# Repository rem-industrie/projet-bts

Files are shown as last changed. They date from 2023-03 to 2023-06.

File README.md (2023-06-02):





## Projet bts
## Contenu github
* [Info General](#Info-General)
* [Contenu](#Contenu)
* [Technologies](#technologies)
* [Schéma structurel](#Schéma-structurel)
* [Carte](#Carte)
* [organigramme](#organigramme)
* [Boîtier 3D](#Boîtier-3D)
* [Setup](#setup)

## Info General
Ce projet consiste à capter le courant et une fois fait le renvoyer sur une passerelle MQTT envoye en RS232.

## Contenu
Ce github contient:
* Fichier stl et gcode
* Fichier ARES ISIS.
* Documentation
	
## Technologies
Projet est crée avec:
* Un arduino uno
* Alimenté en +28V
* Carte A4049 (capteur de courant)

## Schéma structurel

schema1
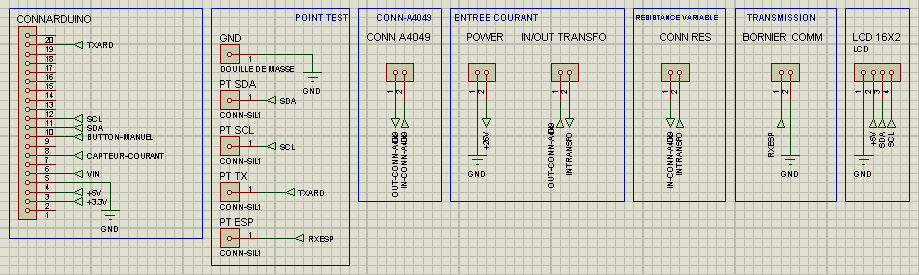
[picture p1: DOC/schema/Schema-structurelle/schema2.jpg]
schema2


## Carte
ares

## organigramme
projet bts

## Setup
Pour cloner le projet:

* ## Boîtier 3D




```
gh repo clone rembot-industrie/projet-bts

```

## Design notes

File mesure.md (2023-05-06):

## Projet bts

## Type mesure:
* [1. Capteur ASC712](#1.-Capteur-ASC712)
* [2. Mesure RS232](#2.-Mesure-RS232)
* [3. Mesure autre](#3.-Mesure-autre)
* [4. Test capteur](#4.Test-capteur)

## 1. Capteur ASC712

| Capteur : | |
|  :--- | :--- |
| Tension ALIM  | +5V |
| Tension à vide  | +2.50V |
| Sensibilité | 40mV/A |
| Marche d'erreur | ±0.8% |

Formule pour obtenir la Tension à partir du courant:
- courant(A) x sensibilité(40mV)

| Tension |  **Mesure Capteur(V)** |  **Mesure Capteur(A)** | Calcul |
| :--- | :--- | :---: | :---: |
| +0V | +2,50V | +0A | +0V |
| +5V | +2,50V | +0.07A | +0.028V |
| +9V | +2,51V | +0.25A | +0.1V |
| +15V | +2,51V | +0.31A | +0.124V |

## 2. Mesure RS232
Ce projet consiste à capter le courant et une fois fais le renvoyer sur une passerelle MQTT envoyer en RS232.
mesure final test

- Regulateur

| Pins | Tension |
| :--- | :--- |
| ADJ(1) | +6.22V |
| VO(2) | +7.50V | 
| VIN(3) | +15V (change selon l'alim)|

- Mesure Transmission:

| | Tension |
| :--- | :--- |
| TX | +4,70V |
| ESP | +3.37V | 
| SCL | +4.99V |
| SDA | +4.99V |

- Button:

| | Tension |
| :--- | :--- |
| Entré | +4.95V |
| Sortie | +1.80V |

- Capteur:

| | Tension |
| :--- | :--- |
| Vcc | +5V |
| Out | +2.5V voir +2.49V  |

- Mesure:

| | Tension |
| :--- | :--- |
| Vin-ard | +7,47V |
| +5 ard | +5V |
| Alim-led | +2.10V |
| led-led | +4.70V |

## 4. Test capteur

| Nombre ampoule(s) 2W |  Nombre ampoule(s) 10W |  **Mesure Capteur(A)** | Calcul | Tension(V) |
| :--- | :--- | :---: | :---: | :---: |
| 0 | 0 | +0A | +0V | +2.49V |
| 0 | 1 | +0.80A | +0.8V | +2.52V |
| 0 | 2 | +1.66A | +1.6V | +2.56V |
| 1 | 2 | +1.90A | +1.84V | +2.57V |
| 2 | 2 | +2.14A | +2.08V | +2.58V |
| 3 | 2 | +2.39A | +2.32V | +2.59V |

Calcul: P / U

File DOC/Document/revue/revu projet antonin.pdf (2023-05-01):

Antonin
Barreau

# Revu de projet

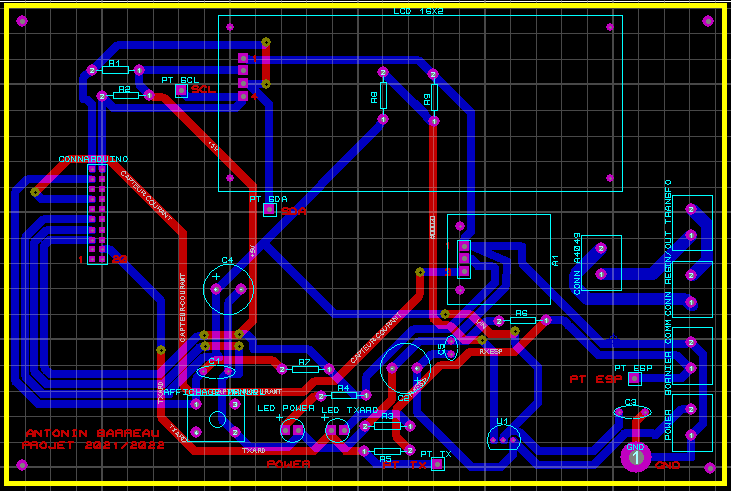
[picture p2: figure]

Lycée Pierre de Coubertin
Année 2022-2023
1/18

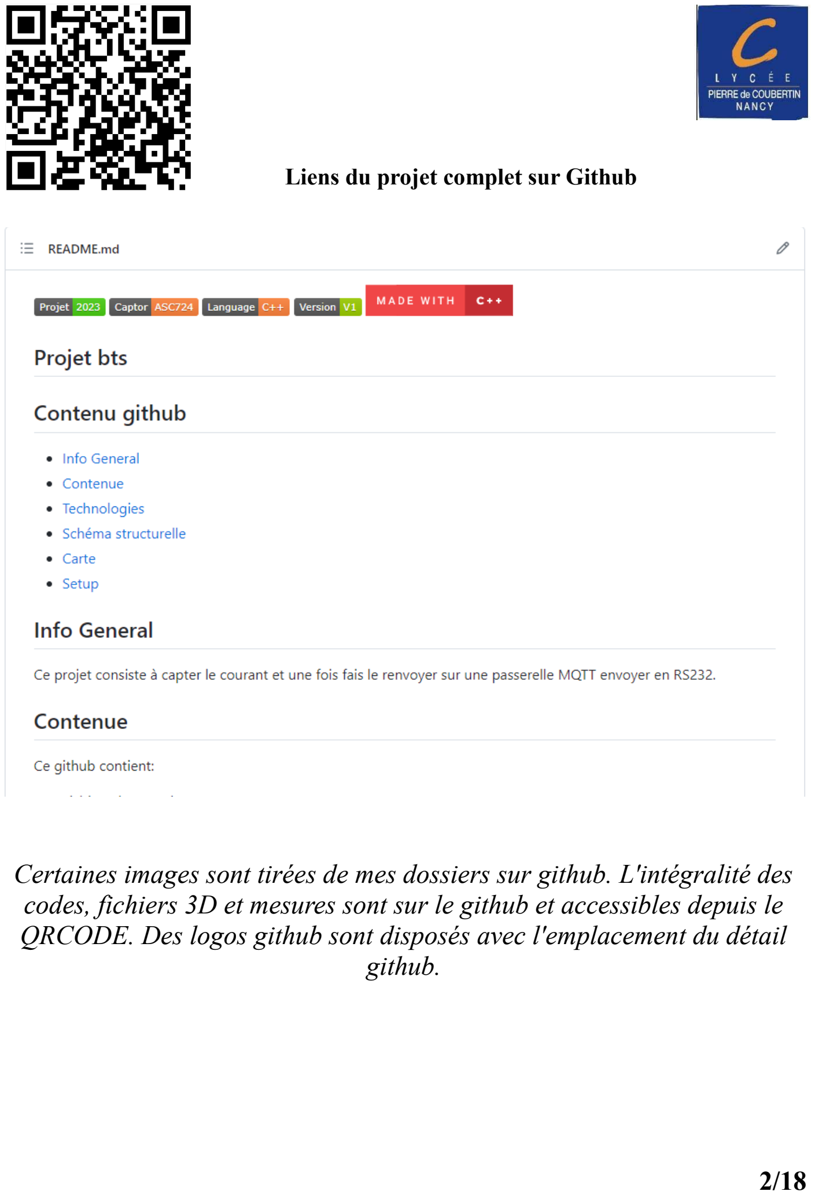
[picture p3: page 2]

Liens du projet complet sur Github

Certaines images sont tirées de mes dossiers sur github. L'intégralité des codes, fichiers 3D et mesures sont sur le github et accessibles depuis le QRCODE. Des logos github sont disposés avec l'emplacement du détail github.

2/18

# Sommaires :

## Projet globale :

- Présentation projet globale | page 4
. Commanditaire du projet | page 5

## Sous projet :

- Présentation sous projet | page 6
- Les composants utilisé | page 7
- A4049 | page 8
- Étude des composants | page 9
- La mise en œuvres du projet | page 10
(phase de test et problème rencontré, mesures)

## Conception :

- Schéma structurelle | page 11
- Conception de la carte à l'aide de logiciel assisté | page 14
- Étude du programme | page 15
- Boîtier 3D | page 17

3/18

# Projet Globale :

par le BUT GEII. Il faudra réaliser un prototype avec les solutions qui nous seront imposées, ou chercher les plus appropriées (micro-contrôleur ex : arduino, esp, raspberry), avec différents capteurs, et ensuite envoyer sur un serveur MQTT réalisé par le BUT.

Le projet est découpé en plusieurs sous-parties :

- Aide au dimensionnement des dissipateurs thermiques
- Aide au dimensionnement du transformateur d'alimentation (mon projet)

Toutes les cartes seront alimentées par une carte d'alimentation qui fourni du +27V (environ), fournie par l’établissement et qui régule la tension selon le contrôleur et la carte.

4/18

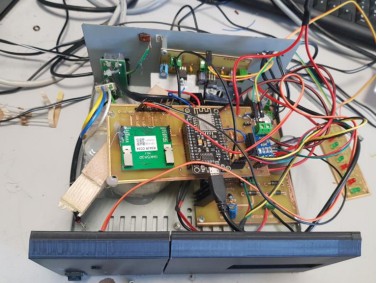
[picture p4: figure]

# Commanditaire :

Pour ce projet, le lycée Pierre de Coubertin est en partenariat avec la formation GEII « Génie électrique et informatique industrielle ». Monsieur François Gremillet, professeur d'électronique dans le lycée Pierre de Coubertin et qui intervient dans la formation GEII.

Un partenariat a vu le jour suite à la présentation de son projet « station audio » qui met en œuvre le fonctionnement de nombreux composants électroniques étudiés dans la formation.

La formation :

Le but GEII est formation de niveau BAC+3 (licence). Cette formation est sur 3 ans avec :

- 600h de projet.
- 30h-33h de cours /semaine
- 22 à 26 semaines de stage.
- Travaux de groupe.

5/18

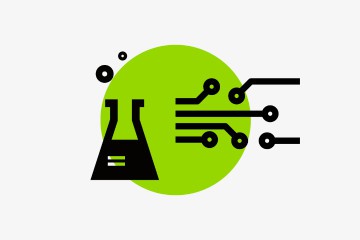
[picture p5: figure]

# Présentation de mon sous-projet :

Extrait cahier des charges : « Création d’une carte de mesure de courant sur transformateur avec envoie des données sur le serveur MQTT. »

En solution imposé :

Micro-contrôleur | Arduino
Capteur effet hall | ACS724 (A4049)
Écran | Afficheur I²C « Quapass U1 »

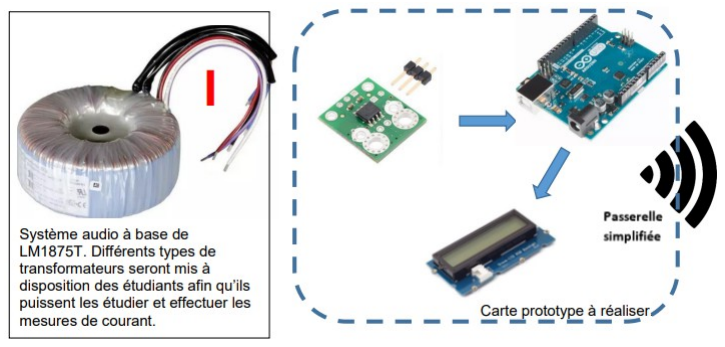
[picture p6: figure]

But du projet : Prise de mesure avec un capteur à effet hall avec le capteur ASC724 et sa carte d'adaptation A4049.

6/18

# Les composants utilisé :

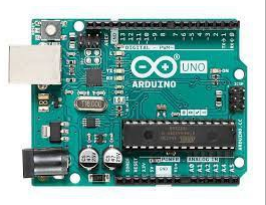
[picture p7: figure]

Micro-contrôleur | Arduino | Sert pour envoyer le code, et alimente une partie du projet . Il envoi les information à la passerelle MQTT.

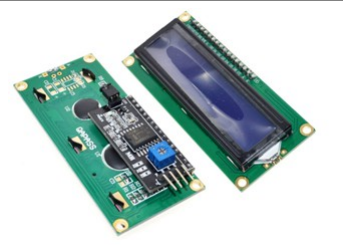
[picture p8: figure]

Ecran I2C | Quapass U1 | Affiche la tension et le courant.

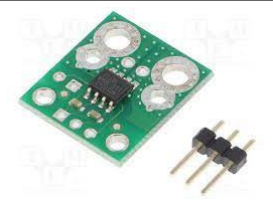
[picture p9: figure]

Capteur de courant | ASC724 (A4049) | Capte le courant entrant et il envoie une tension sur le pin analogique de l'arduino et le convertira pour avoir le courant.
Régulateur tension | LM317 | Régule le courant entrant (+30V) en +7.40V pour l'arduino

Résistances et condensateurs

Bouton | | Pour activer la fonction « Prise de courant automatique »
Borniers (24A) | CTB0700 /2

7/18

A4049 :

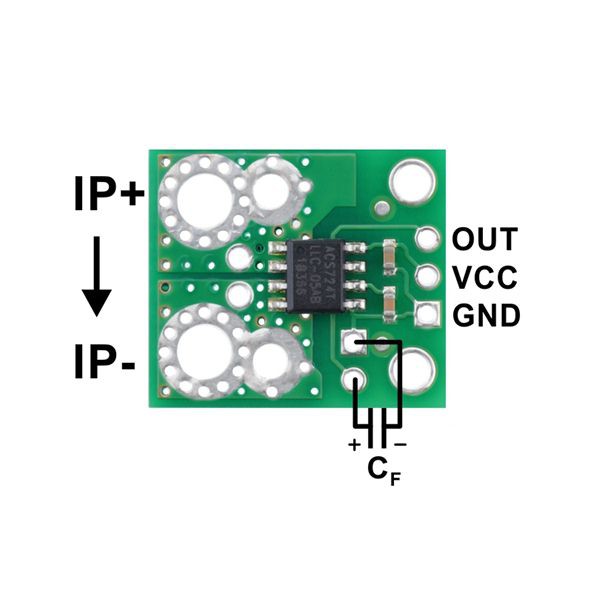
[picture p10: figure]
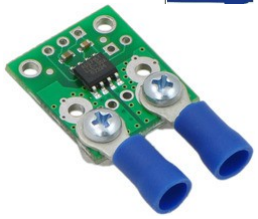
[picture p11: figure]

La carte A4049 est un capteur de courant à effet hall. Il existe en plusieurs versions selon le modèle. Il encaisse plus ou moins d'Ampérage (le modèle utilisé est un +50A/-50A).

Tension d'entrée | +4,5V / +5V
Sensibilité | 40mV / A
Tension de sortie | +2,5V
Erreur typique | ±0,8 %
Version | Bidirectionnelle
Plage de température | -40°C à 150°C
Courant | De -50A/+50A

La carte est une « carte porteuse » ou « carte porteuse » pour le capteur ACS724. La carte fonctionne en AC/DC.

Pour connaître le courant envoyé par le A4049, le calcul : P/U

Pour le courant : (X- 2,5)/(0,40)

*X : Le voltage reçu sur le pin analogique.

8/18

(mesure.md)

# La mise en œuvres du projet

Mon projet est de mettre en œuvre mon capteur A4049 avec un arduino (solution imposée) comme micro-contrôleur. Je dois ensuite faire une mesure de courant avec celui-ci, le renvoyer sur un afficheur I²C, et le renvoyer en RS232.
Les données seront envoyées en RS232. La tension devra être adaptée car la passerelle est gérée par un esp (qui est un équivalent de l'arduino, en version réduite), qui prend du 3.3V. Hors, l'arduino lui envoie du 5V et il y a un risque pour la passerelle.

J'ai donc réalisé un pont diviseur et j'ai rencontré un problème avec celui-ci lors de mes tests

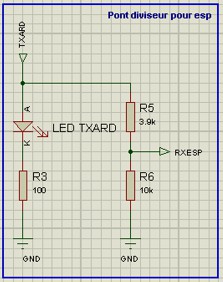
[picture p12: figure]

A l'origine il était comme ceci

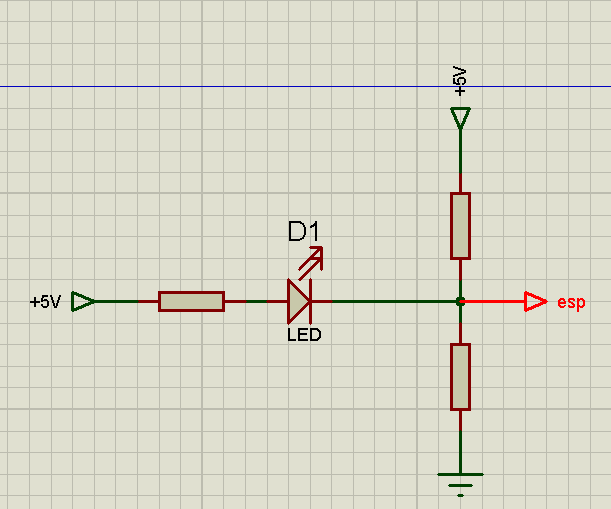
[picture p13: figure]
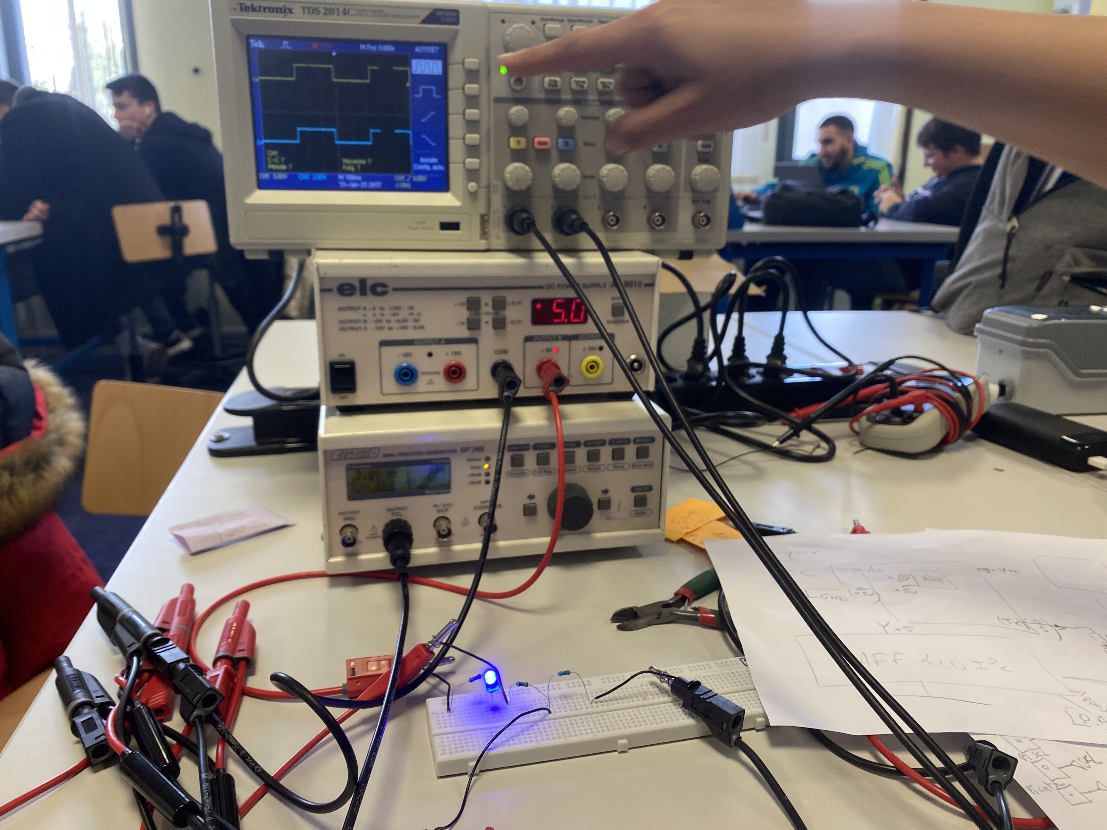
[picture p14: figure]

Le problème est que la résistance qui protège la led faisait diminuer la tension avant le pont diviseur qui abaissait la tension bien dessous des 2V.

9/18

# Mesures :

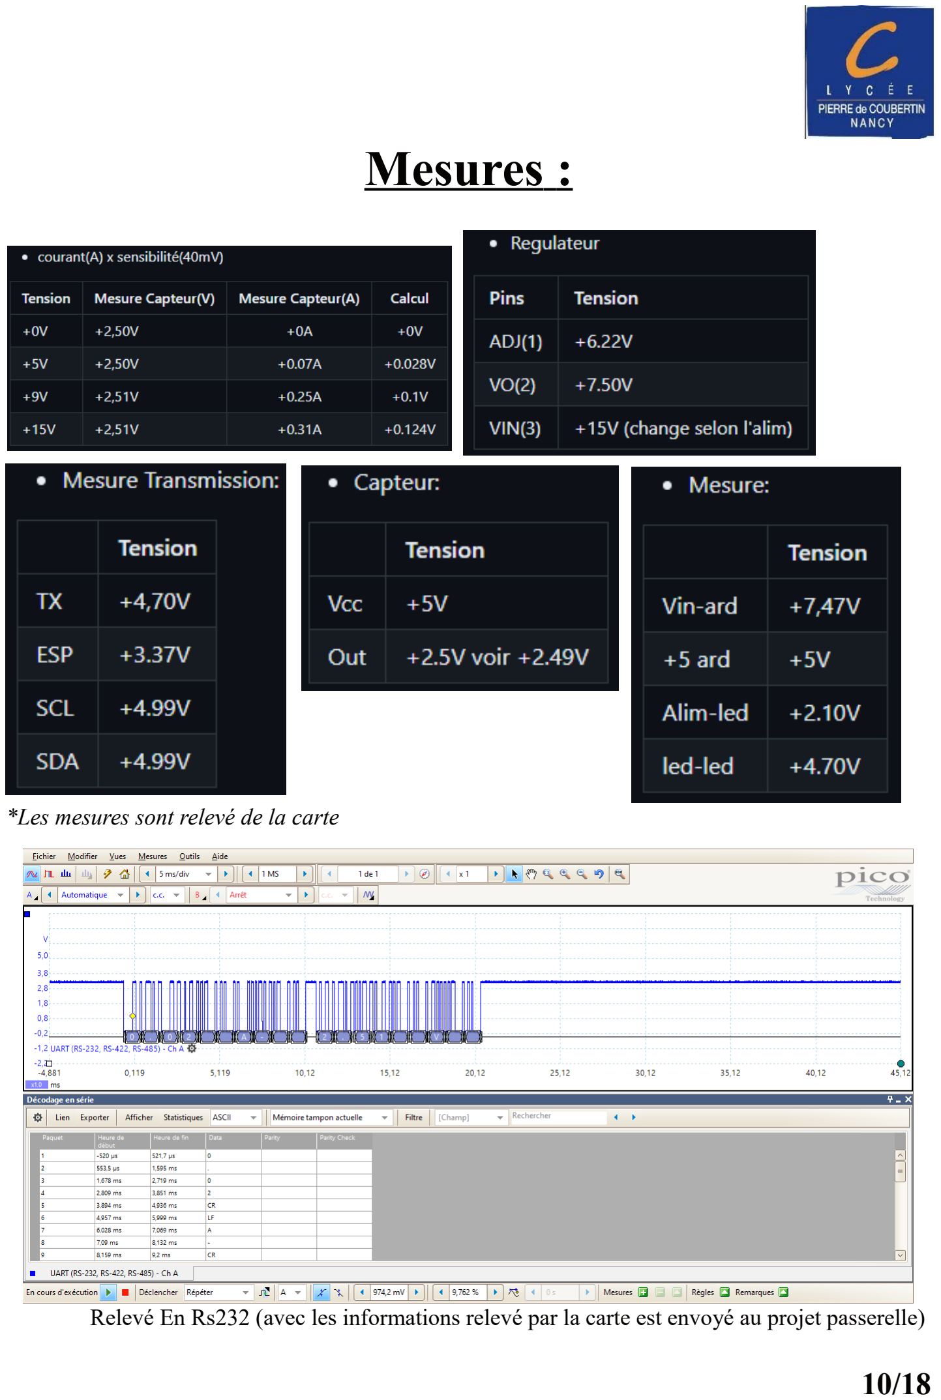
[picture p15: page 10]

*Les mesures sont relevé de la carte

Relevé En Rs232 (avec les informations relevé par la carte est envoyé au projet passerelle)

10/18

# Conception :

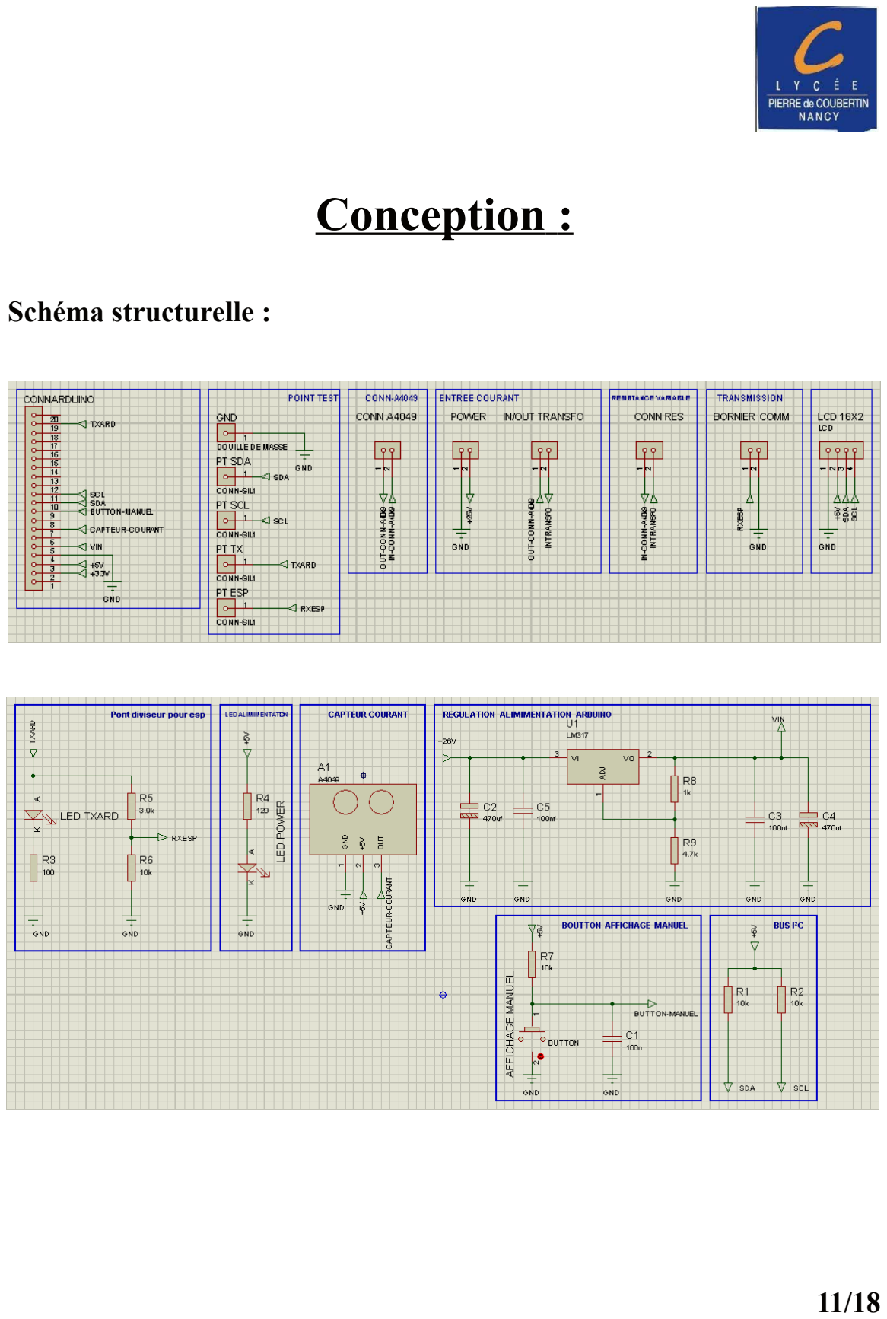
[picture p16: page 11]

Schéma structurelle :

11/18

Le pont diviseur pour adapter pour la passerelle

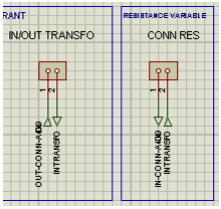
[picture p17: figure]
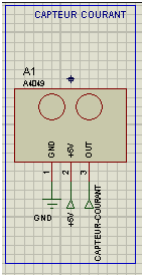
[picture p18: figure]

Cette partie est pour le capteur de courant, un premier bornier sert à brancher l'entrée secondaire du transformateur.

Ce bornier va ensuite sur un second bornier où on met une résistance pour faire une consommation sur le système.

Il est branché sur un troisième bornier qui est sur les COS du A4049 et revient sur le bornier du transformateur
12/18

Pour Pour | Pour l'écran I²C j'ai mis 2 résistances de 10k

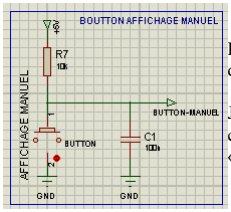
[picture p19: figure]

La platine est pourvue d'un bouton qui permet
de passer en mode « Mesure automatique »

J'ai mis un condensateur pour lisser le
courant et éviter tout parasite. Le condensateur sert « d'anti-rebond ».

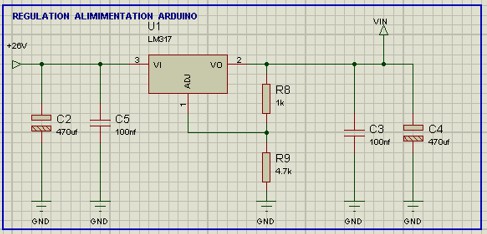
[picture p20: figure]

Le régulateur qui régule +26V en +5V pour l'arduino.

13/18

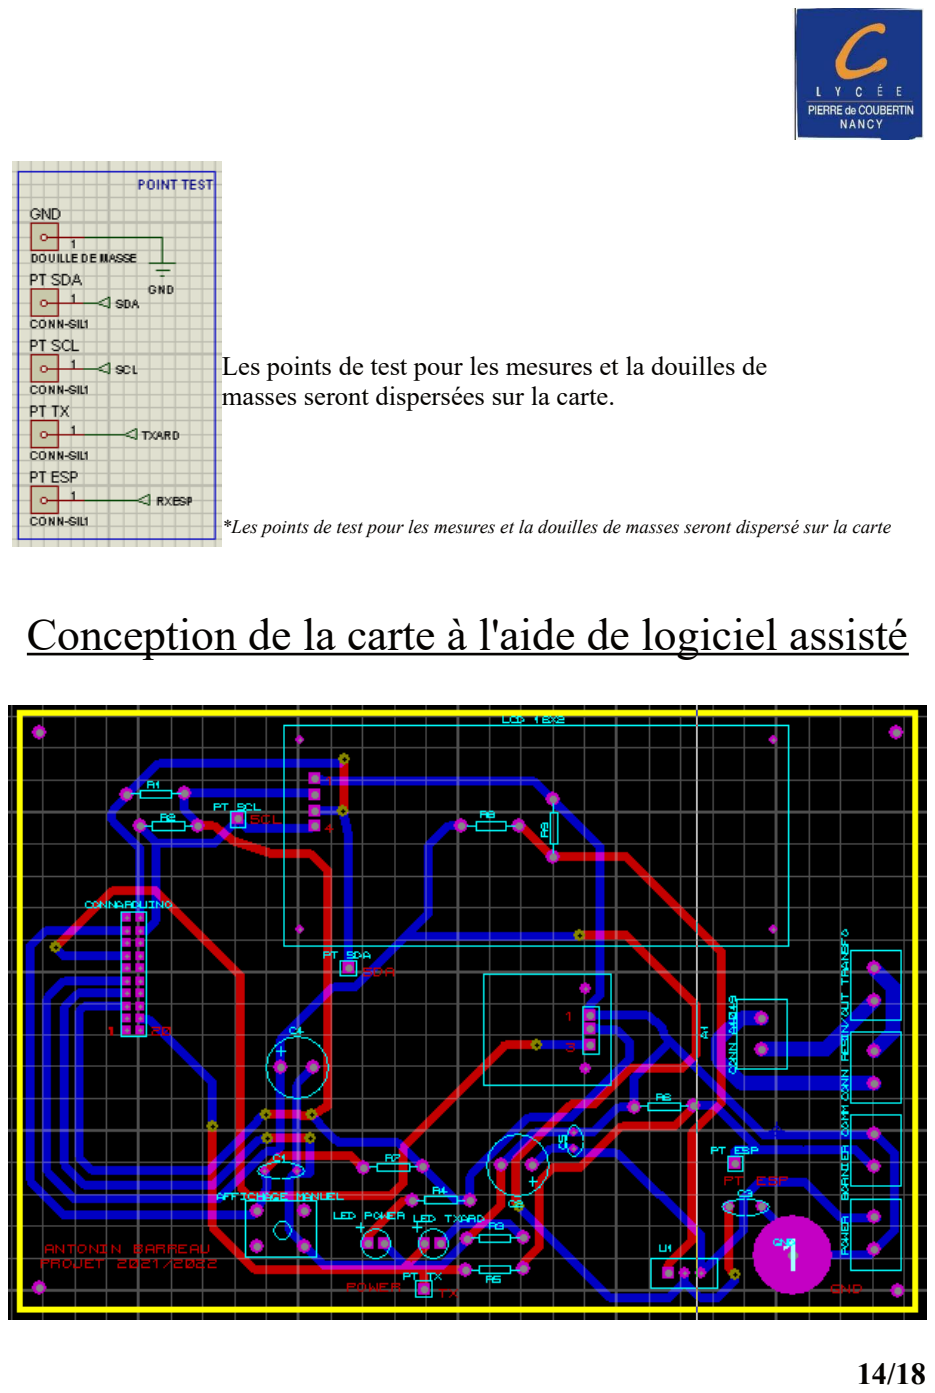
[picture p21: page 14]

Les points de test pour les mesures et la douilles de masses seront dispersées sur la carte.

*Les points de test pour les mesures et la douilles de masses seront dispersé sur la carte

# Conception de la carte à l'aide de logiciel assisté

14/18

L'image-ci dessus est mon schéma d'implantation. La carte était conçue de sorte à ce qu'un boîtier soit intégré sur la carte. Tous les borniers sont du côté droit de la carte pour une raison de pratique. Le régulateur lm317 est quant à lui placé en bordure de carte le plus éloigné possible car il chauffe.

Ce schéma d'implantation n’est pas le même que la carte. Il y a quelques modifications comme le sda, scl qui n’était pas bien relié, les pistes qui étaient trop collées, la douille de masse qui était juste en taille, et l'empreinte du capteur qui avait une légère erreur de taille.

Pour le capteur, il y a en tout 3 borniers, 1 pour l'entrée du courant (transformateur par exemple), un bornier où l'on peut brancher un système (ex : des ampoules) pour tirer du courant et pour que cela soit plus pratique un bornier pour brancher le A4049.

# Le code :

Pour le code, seule une petite partie est exposée dans cette revue (voir sur github ou doc technique). Pour comprendre mon code voici un organigramme :

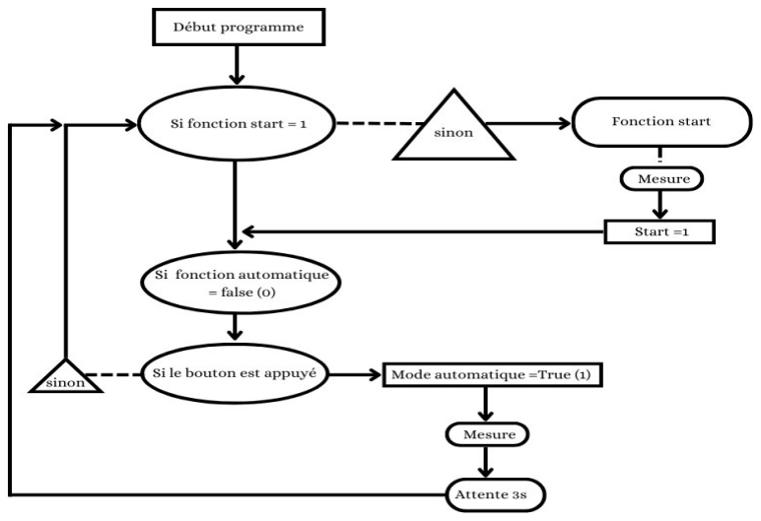
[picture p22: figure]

15/18

(final/finalV4)

void measure()
{
int | adc | = | analogRead(A0); | // | Définit pin de lecture sur le pin
Analogique A0
float | voltage | = | adc | * | 5 | / | 1023.0; | | | // | Converti la tension
float | current | = | (voltage | - | 2.50) | / | 0.04; | // | Converti le courant (Sensibilité 4OmA)
if | (current | <= | 0)
{ | // | Si le courant est inférieur ou égale à 0 il n'affiche que 0
// | Envoie dans la console le courant et tension Toutes les 8s
// | affichage écran
lcd.clear();
lcd.print("Tension: | | | | ");
lcd.print(voltage);
lcd.print("V");
lcd.setCursor(0, | | 1);
lcd.print("Courant: | | ");
lcd.print("0A");
// | Envoie passerelle

Serial.println("Envoie Courant sur la passerelle");

mySerial.println(current); | | // | Envoie du courant
mySerial.println("0A-");
// | Console retour test uniquement
Serial.println("0A");
mySerial.println(voltage); | // | Envoie du courant
mySerial.println("V");
// | Console retour test uniquement
Serial.println(voltage);
}
else
{
// | affichage écran
lcd.clear();
lcd.print("Tension: | | ");
lcd.print(voltage);
lcd.print("V");

lcd.setCursor(0, 1);
16/18

lcd.print("Courant: ");
lcd.print(current);
lcd.print("A");

// Envoie passerelle

Serial.println("Envoie Courant sur la passerelle");

mySerial.println(current); // Envoie du courant mySerial.println("A-");
// Console retour test uniquement Serial.println(current);

mySerial.println(voltage); // Envoie du courant mySerial.println("V");
// Console retour test uniquement Serial.println(voltage);
}
}

# Boîtier 3D :

Pour ce projet j'ai décidé de faire une boîte en impression 3D.
J'ai utilisé Fusion 360 et crée la boîte entièrement

Dimension de la carte :

Largeur | Longueur
9,7cm (97mm) | 14,5cm (145mm)

Sur le modèle 3D j'ai ajouté 12cm sur la longueur & largeur. Soit

2mm | Pour l'épaisseur des bords du boîtier
10 | Pour les vis il y un arc de 10mm par rapport au coins
17/18

Un aperçu depuis le logiciel « Fusion 360 » :

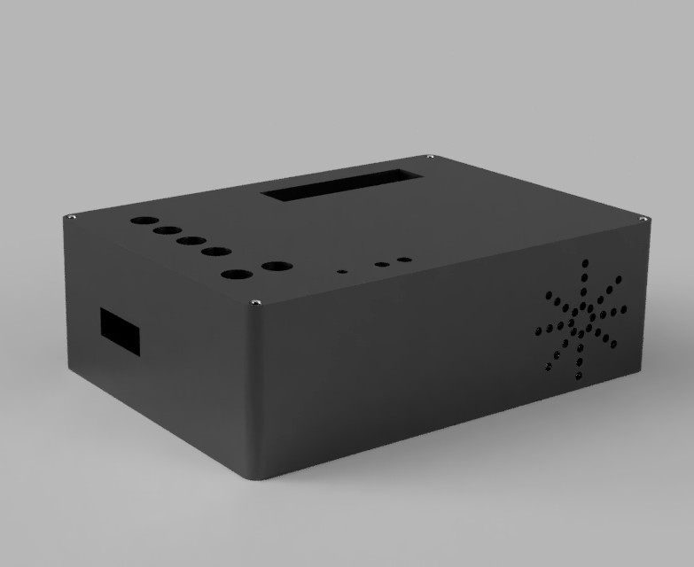
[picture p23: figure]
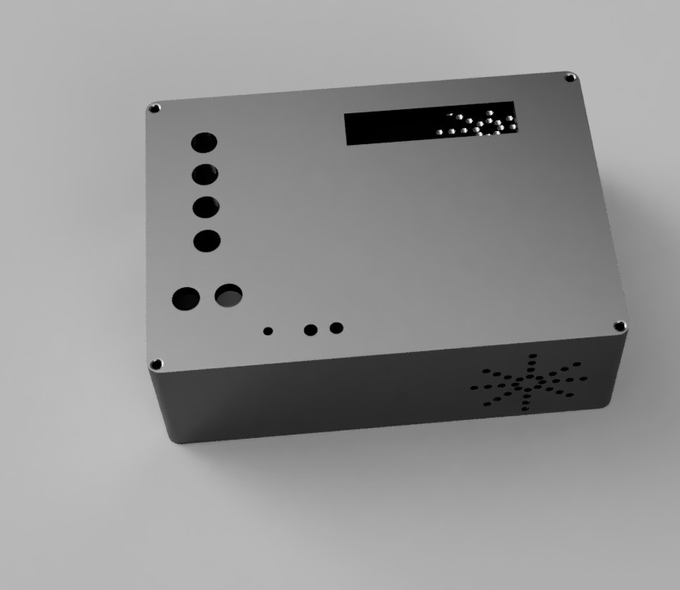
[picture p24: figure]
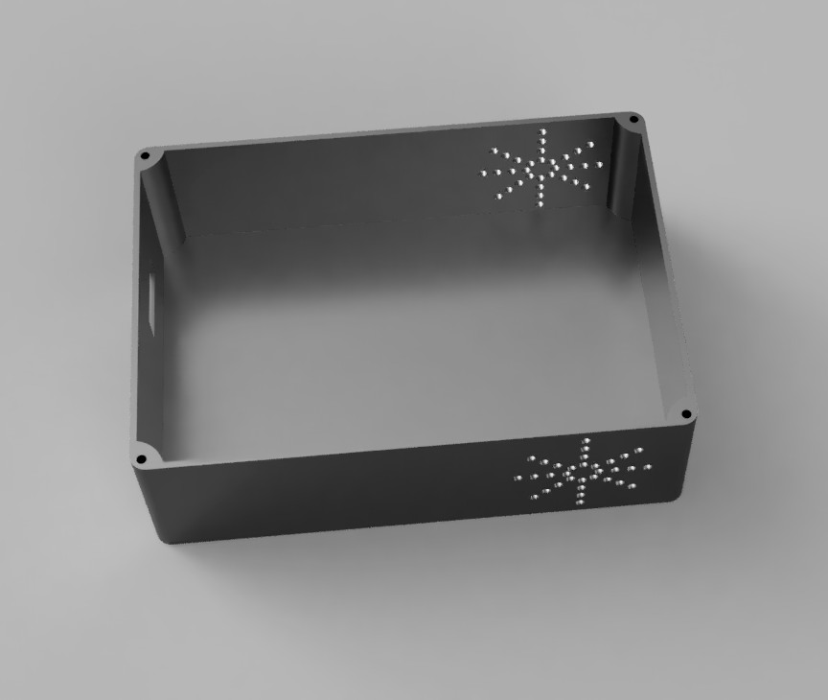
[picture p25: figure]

Le boîtier est fais de sorte à ce que l'air puisse être évacuer par les aérations côté droit. Des trous pour les vis sont disposés aux 4 coins de la boite avec un un trou d'environ 1cm max.

Il y un trou côté gauche pour la nappe de l'arduino.

Concernant les 6 trous sur le couvercle ils serviront pour y mettre points test pour pouvoir y brancher un câble de labo et pour éviter de plier ou casser le boîtier le couvercle à un épaisseur de ~5mm

Tout ceci renforce le prototype, et permet d'éviter de débrancher quoi que ce soit sur la platine durant les tests, ou même des courts-circuit voir de l'abîmer. Sans oublier l'esthétisme avant tout.

18/18

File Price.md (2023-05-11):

Bornier vert: 1,02 => 120,00 €
Bande de connecteur: 2,81 =>
Pins test: 2,81 =>
Capteur: 17,10 =>
Nappe: 1,14 / lot (2 unités) =>
LM317: 0,63 / pièce
Connecteur banane: 0,45 / pièce
Ecran: 0.68
DISSIPATEUR: 0,38
Plaque: 9,80€/2pcs
Res: 12,99€
CONDO 470uf : 6,90€ / 10pcs
condo 100nf: 1,79/ 10pcs 
_______________________________

Bornier vert: 1,02
conn => 0,239
test => 0,239
Capteur: 17,10
Nappe: 0,57
LM317: 0,63
Connecteur banane: 0,45
Ecran: 2,09
DISSIPATEUR: 2,15
Plaque: 4,9

Res: 2€
CONDO 470uf : 0,86
condo 100nf: 0,25
arduino: 9.99

= 42,25

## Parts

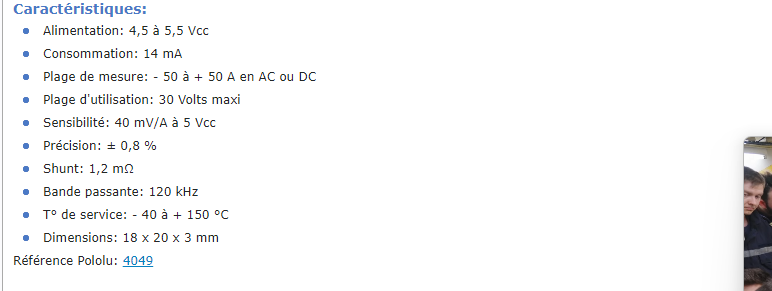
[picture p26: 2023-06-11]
DOC/component/picture/CARACTERISTIQUE.png

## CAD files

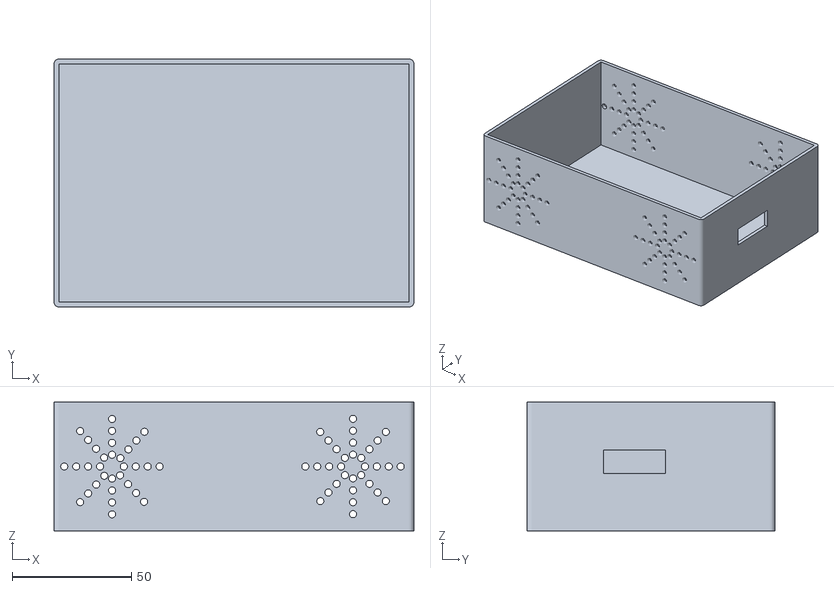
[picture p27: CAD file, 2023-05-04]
3d print/stl/boitier/Boitier projet bas.stl
151.0 x 104.0 x 54.0

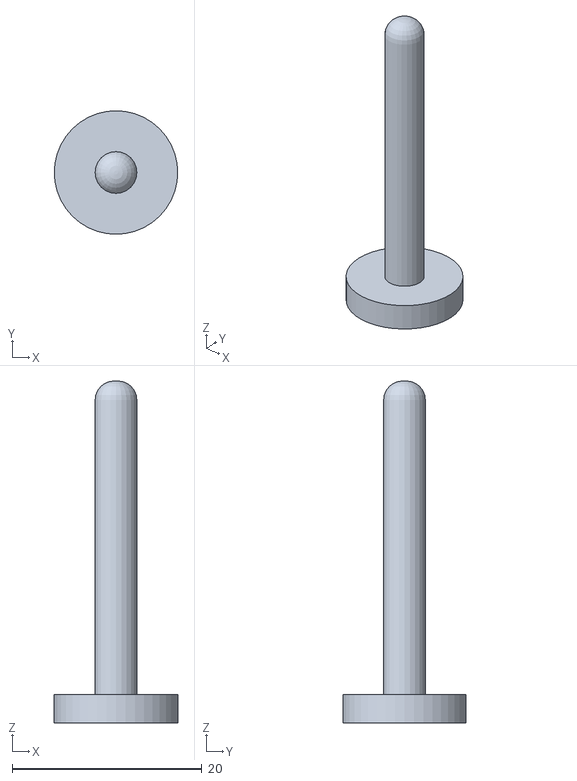
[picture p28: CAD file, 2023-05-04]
3d print/stl/bouton/button.stl
13.0 x 13.0 x 36.0

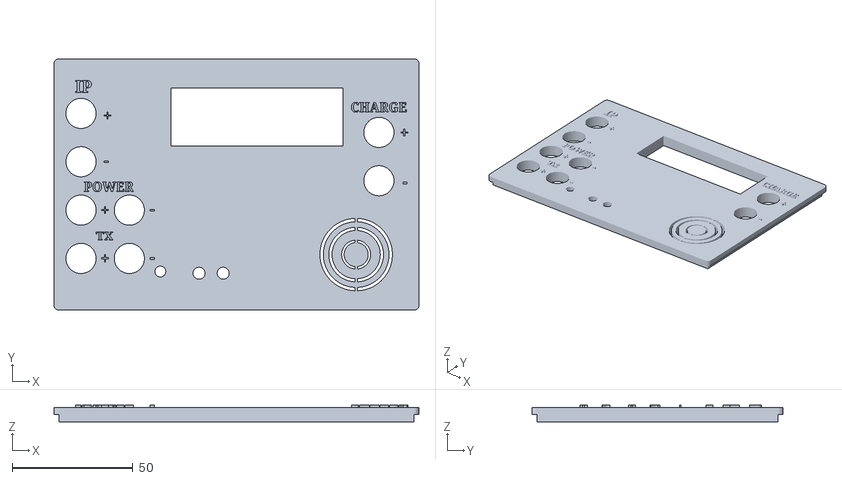
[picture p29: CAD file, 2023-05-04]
3d print/stl/couvercle/haut avec texte/HAUT AS.stl
151.0 x 104.0 x 7.00

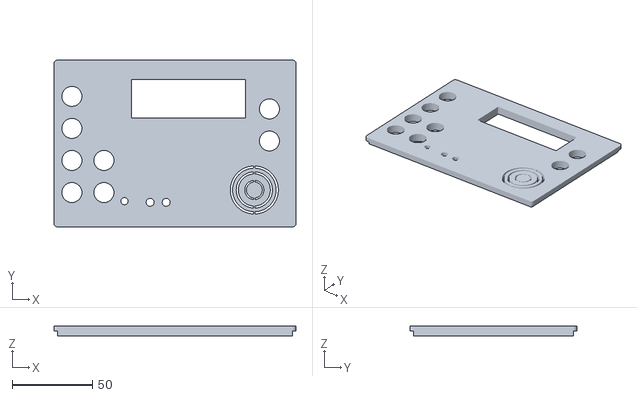
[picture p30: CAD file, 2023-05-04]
3d print/stl/couvercle/haut sans texte/HAUT SS V2.stl
151.0 x 104.0 x 6.00

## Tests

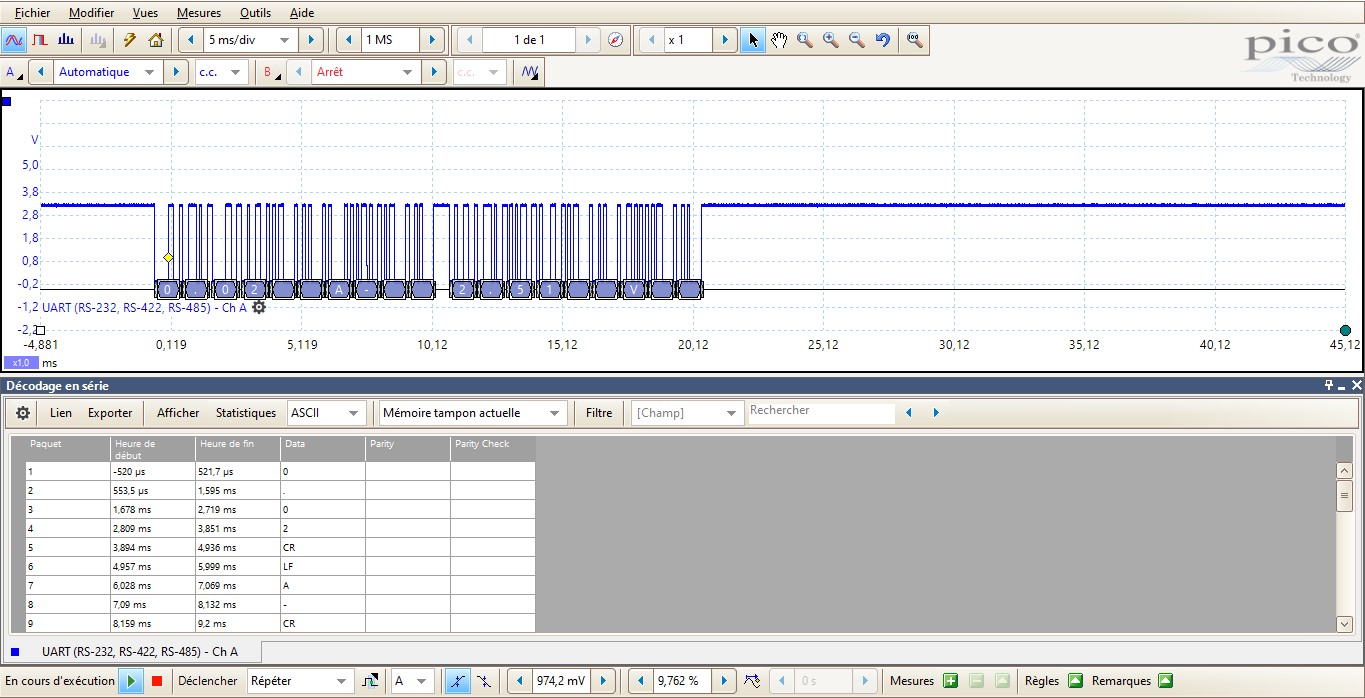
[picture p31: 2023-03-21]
DOC/osciloscope/RS232-TRAME/mesure final test.png

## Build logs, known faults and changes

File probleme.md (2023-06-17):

## Projet bts
## Problème carte
* [1. Court-circuit entre le VIN et le GND](#1.-Court-circuit-entre-le-VIN-et-le-GND)
* [2. Sous alimentation VIN arduino](#2.-Sous-alimentation-VIN-arduino)
* [3. Problème led TX](#3.-Problème-led-TXD)
* [4. Problème SDA, SCL](#4.-Problème-SDA,-SCL)
* [5. Problème conn-arduino](5.-Problème-conn-arduino)

## Phase de test
Tableau utiliser pour le dépannage.

| **Fonction** | Statut probleme|  Description  | Tension |
| :--- | :---: | ---: | ---: |
| CONN Capteur | Ok | | +5V |
| SDA |  IMPORTANT  |  Problème conception inversion conn | +5V  |
| SCL |  IMPORTANT  |  Problème conception inversion conn | +5V  |
| BOUTON | Ok | | +V |
| LED ALIM |  GRAVE  |  Court-circuit entre Vin et Gnd | +5V  |
| LED RX |  MOYEN |  Court-circuit entre entre les pin led | +5V  |
| ALIM PRINCIPAL | Ok | | +28V |
| VIN |  IMPORTANT  | SOUS ALIMENTATION ARDUINO PONT DIVISEUR  | +7.40V |
| CONN-ARDUINO |  MOYEN  | SOUDURE PINS  | |

## 1. Court-circuit entre le VIN et le GND
Lors de la mise en tension de la carte aucune led ne s'allume après plusieurs recherche il y avait un très léger filet d’étain entre le VIN et le GND comme sur la photo ci-dessous

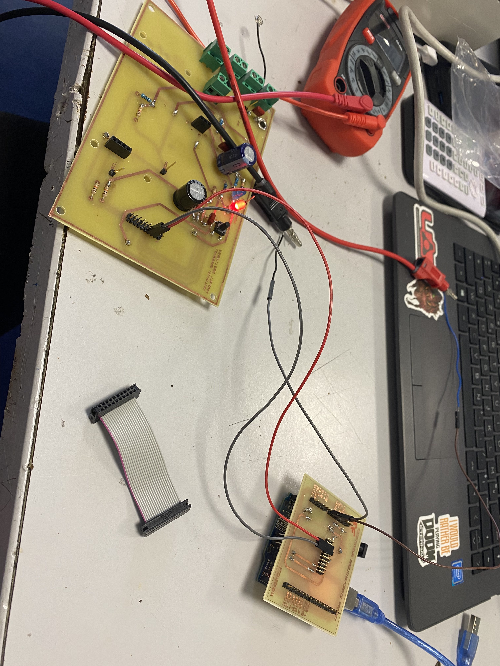
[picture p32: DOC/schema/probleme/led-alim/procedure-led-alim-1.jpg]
procedure-led-alim


- Le probleme:
Dès que la carte est sous tension l'arduino se met en erreur et aucune led sur la platine ne s'allume

- Pour dépanner:
C'est simple j'ai brancher câble par câble pour trouver le court-circuit.
La panne n'a pas était retrouvé avec cette solution.

J'ai ensuite utilisé le multimètre et tester les continuités, j'ai fini par tomber sur le problème.
- Solution: Un coup de cuter entre les pistes.
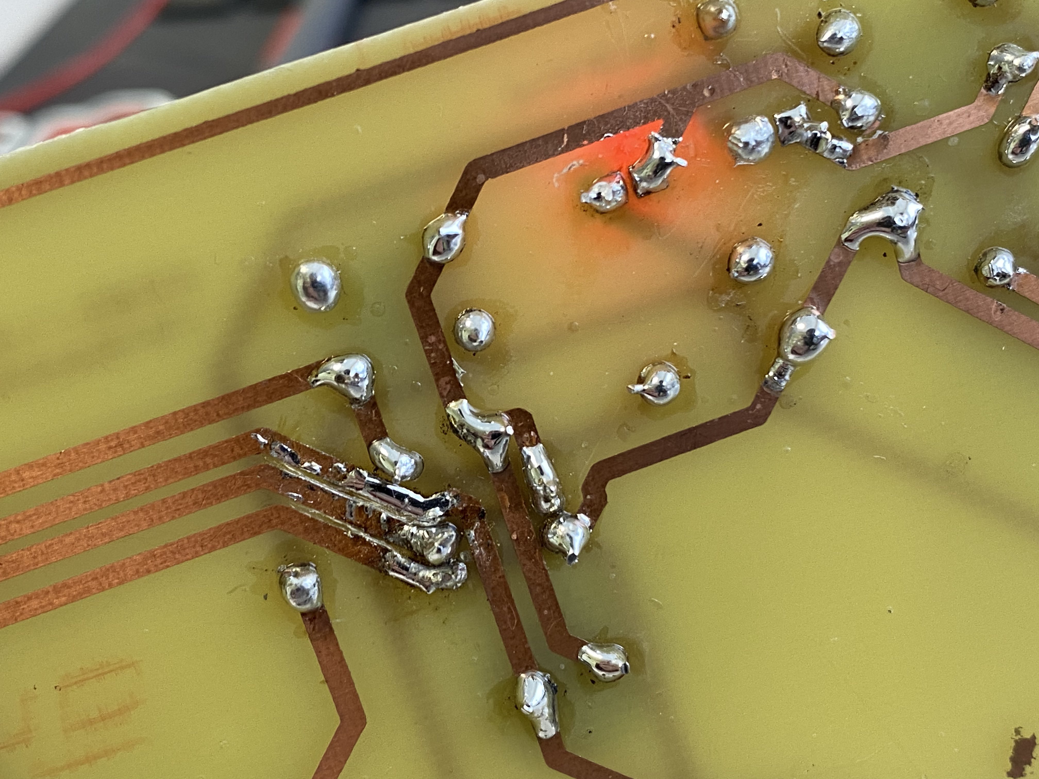
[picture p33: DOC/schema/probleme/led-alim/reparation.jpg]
reparation


## 2. Sous alimentation VIN arduino

Lors de prise de mesure quand la platine est alimenté avec l’alimentation labo l'arduino n'envoie pas la tension « normale » Par exemple il envoyait du +4V au lieu du +5V. Il y a une erreur sur le pont diviseur,
L'arduino s'alimente au vin entre +7V et +12V Avec la prise de mesure a la sortie du régulateur il y avait que du +5V, l'arduino à un régulateur et comme l'arduino était sous alimenté il ne pouvait pas fournir la tension demandé.

En calculant le pont diviseur du régulateur j'ai changé et j'obtiens du environ +7.40V
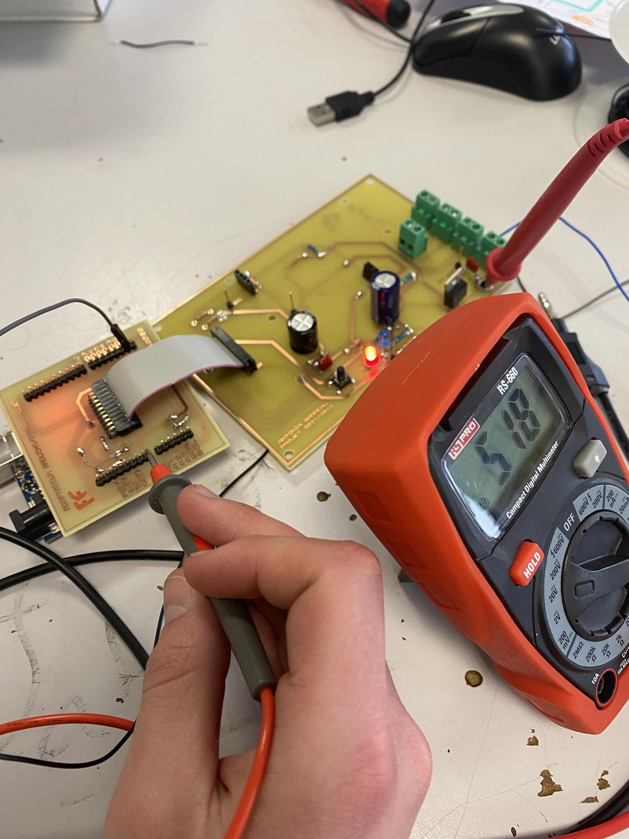
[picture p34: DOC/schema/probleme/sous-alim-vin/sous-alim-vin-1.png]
sousalim1

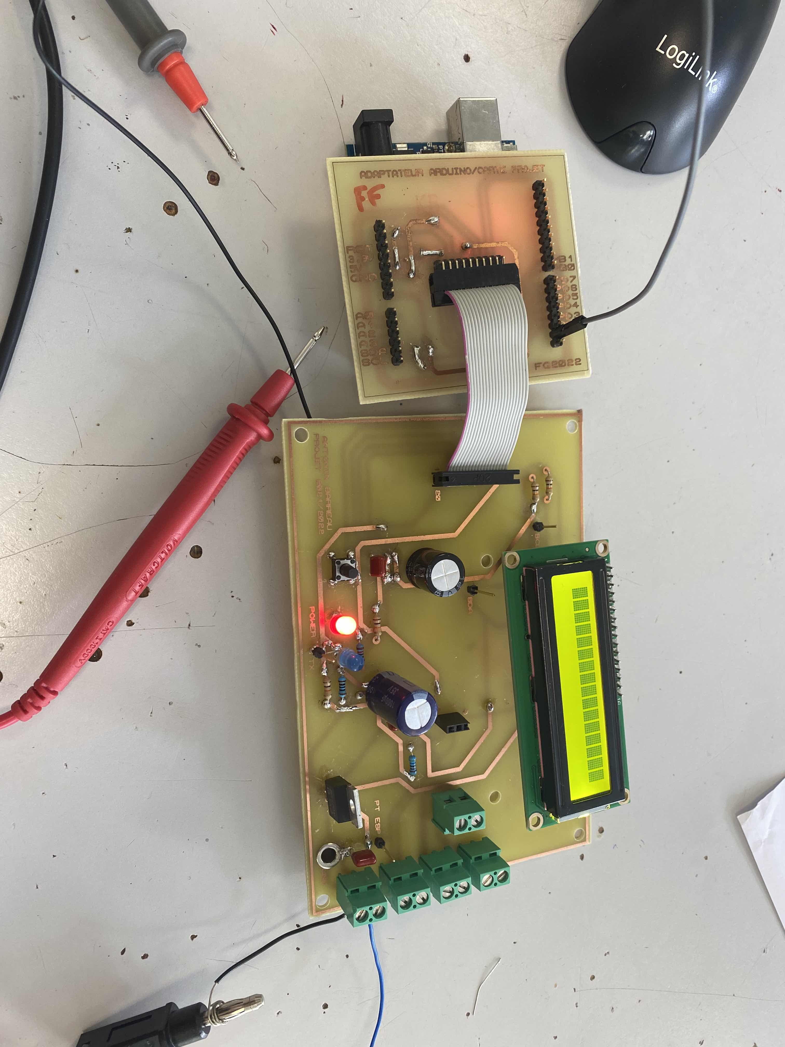
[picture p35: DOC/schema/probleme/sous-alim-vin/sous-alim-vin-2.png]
sousalim2


## 3. Problème led TX

Problème: La led tx ne s'allume pas.

Lors de test la led tx ne s'allume pas.
Pour la tester j'ai utilisé un gbf avec pour le dépanage
| **Fréquence**| Volt (GPP) |
| :--- | :---: |
| 10k | +5 V |

( On utilise le gbf pour simuler le tx de l'arduino)

En regardant la led j'ai vu une soudure raté j'ai simplement mis un coup de cuter et tout s'est mis à fonctionner.

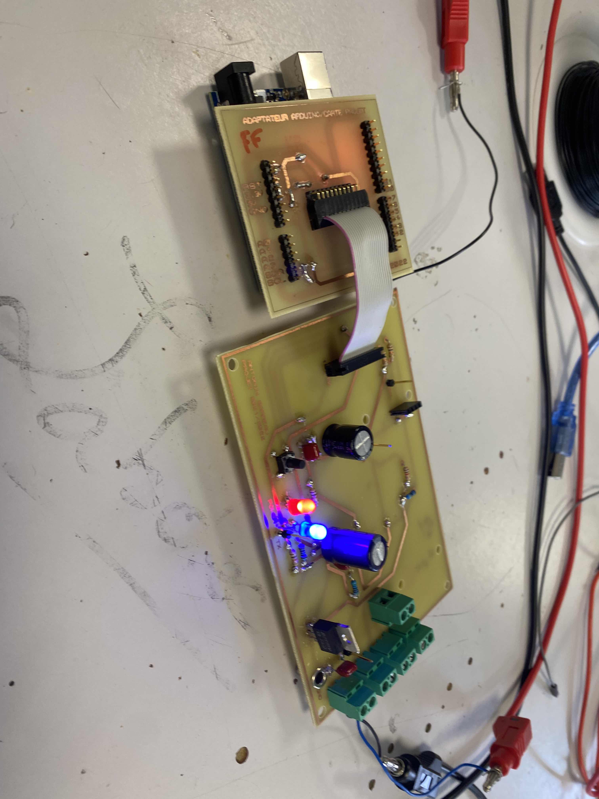
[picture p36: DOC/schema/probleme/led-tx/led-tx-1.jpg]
ledTx1

ledTx2

## 4. Problème SDA, SCL

- Problème : L'écran lcd n'affiche rien.
- Supposition : Inversion conn du conn-arduino lors de la création du schéma structurelle.
- Solution : Coupé les pistes et soudé des cables du connecteurs au pistes.

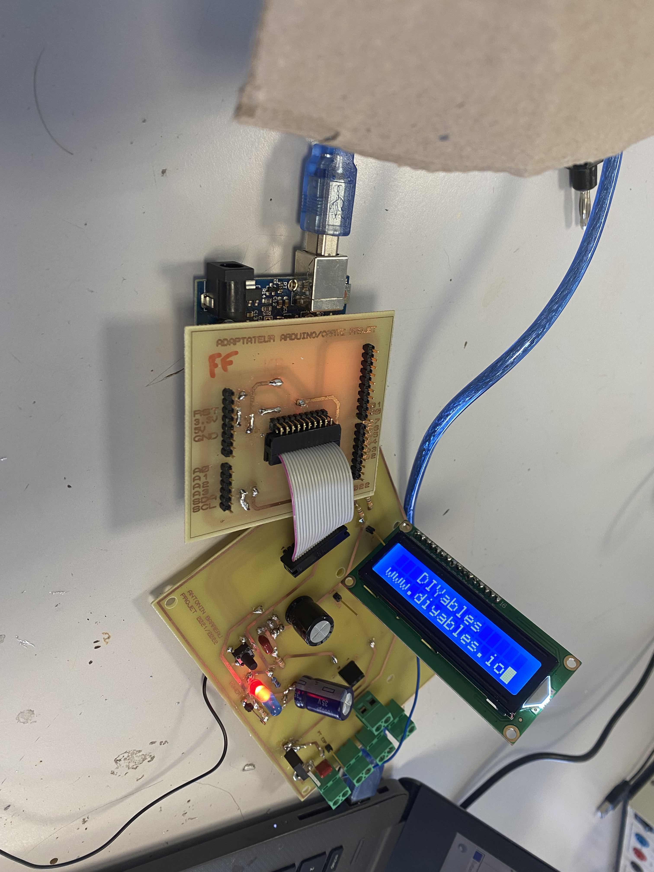
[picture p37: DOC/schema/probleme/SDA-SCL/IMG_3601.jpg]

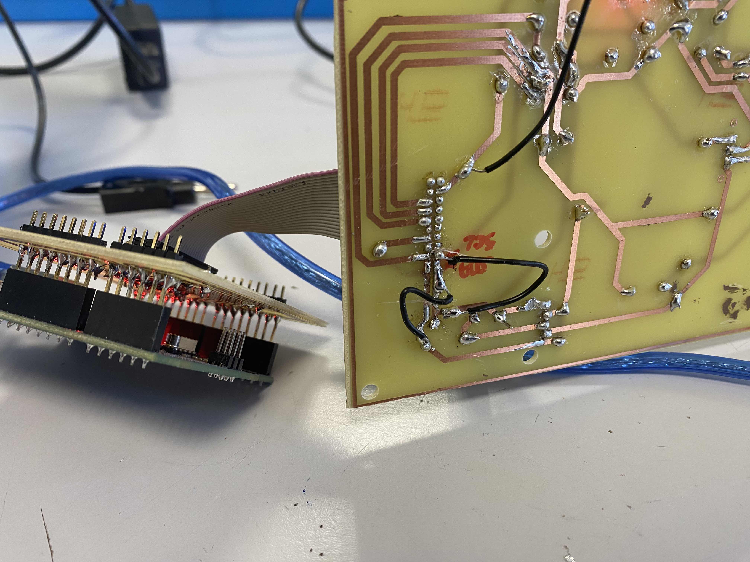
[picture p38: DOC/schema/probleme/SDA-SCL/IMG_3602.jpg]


Il y eu une inverssion de pins ce qui cause une panne problèmatique.

## 5. Problème conn-arduino

- Problème : L'Afficheur à un mauvais contact
- Solution : Ressouder le conn-arduino.

error-pins arduino

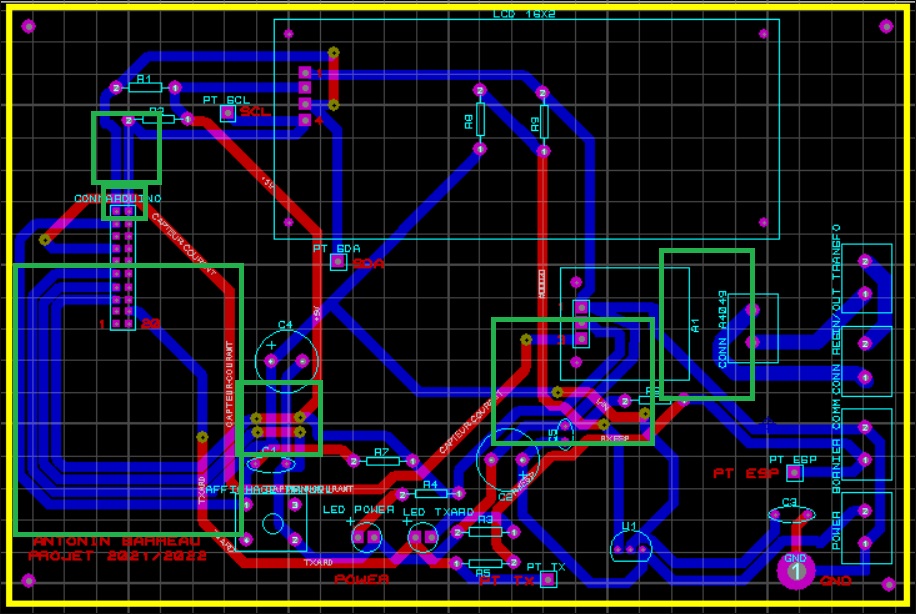
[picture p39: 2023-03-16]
DOC/schema/schema-Implantation/error conception/ares probleme.jpg

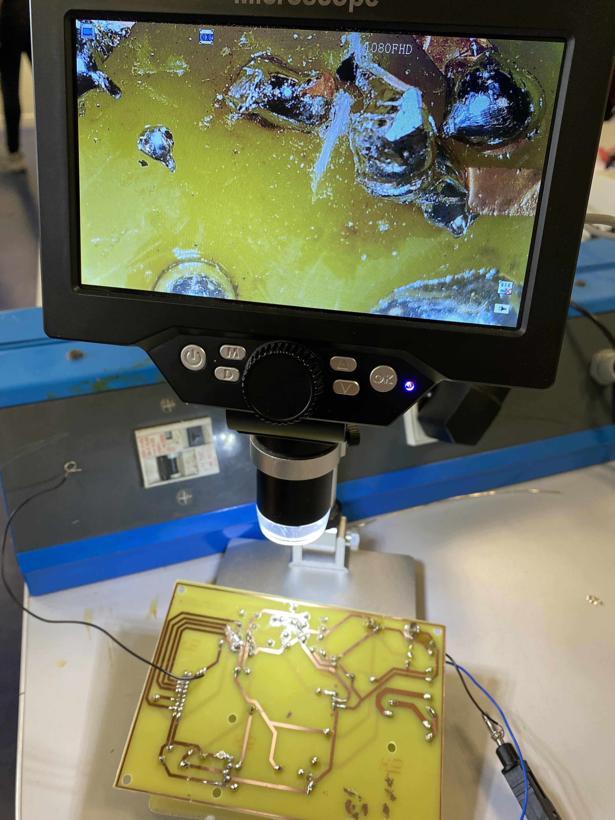
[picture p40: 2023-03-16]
DOC/schema/probleme/led-tx/led-tx-loupe.jpg

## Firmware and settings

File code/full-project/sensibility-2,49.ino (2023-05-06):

// importation librairy
#include <LiquidCrystal_I2C.h>
#include <SoftwareSerial.h>
#include <Wire.h>

// paramétrage
LiquidCrystal_I2C lcd(0x27, 16, 2);
SoftwareSerial mySerial(4, 3); // RX,TX redéfinit par la librairy

const char buttonPin = A2;
const int debit = 9600; // Débit Tx
char Demarrage;         // Boucle demarrage
char MesureLoop = 0;

int buttonState = 1; // Button définit à l'état 1

void setup()
{
    // Ecran initialisé
    lcd.init();
    lcd.backlight();

    pinMode(buttonPin, INPUT); // Entrée bouton

    Serial.begin(debit);
    mySerial.begin(debit);
    Serial.println("Test communication RS232");
    delay(1000);
}

void measure()
{

    int adc = analogRead(A0);                // Définit pin de lecture sur le pin Analogique A0
    float voltage = adc * 5 / 1023.0;        // Converti la tension
    float current = (voltage - 2.49) / 0.04; // Converti le courant (Sensibilité 4OmA)

    if (current <= 0)
    { // Si le courant est inférieur ou égale à 0 il n'affiche que 0

        // Envoie dans la console le courant et tension Toutes les 8s

        // affichage écran
        lcd.clear();
        lcd.print("Tension: ");
        lcd.print(voltage);
        lcd.print("V");

        lcd.setCursor(0, 1);
        lcd.print("Courant: ");
        lcd.print("0A");

        // Envoie passerelle

        Serial.println("Envoie Courant sur la passerelle");

        mySerial.println(current); // Envoie du courant
        mySerial.println("0A-");

        // Console retour test uniquement
        Serial.println("0A");

        mySerial.println(voltage); // Envoie du courant
        mySerial.println("V");

        // Console retour test uniquement
        Serial.println(voltage);
    }
    else
    {
        // affichage écran
        lcd.clear();
        lcd.print("Tension: ");
        lcd.print(voltage);
        lcd.print("V");

        lcd.setCursor(0, 1);
        lcd.print("Courant: ");
        lcd.print(current);
        lcd.print("A");

        // Envoie passerelle

        Serial.println("Envoie Courant sur la passerelle");

        mySerial.println(current); // Envoie du courant
        mySerial.println("A-");
        // Console retour test uniquement
        Serial.println(current);

        mySerial.println(voltage); // Envoie du courant
        mySerial.println("V");
        // Console retour test uniquement
        Serial.println(voltage);
    }
}

void start()
{

    // Démarrage système
    lcd.clear();
    lcd.setCursor(3, 0);
    lcd.print("Projet BTS");

    lcd.setCursor(3, 1);
    lcd.print("2022/2023");

    // Attente de 2s
    delay(2000);

    lcd.clear();
    lcd.print("Initialisation");
    lcd.setCursor(6, 1);

    lcd.print(".");
    delay(1000);
    lcd.print(".");
    delay(1000);
    lcd.print(".");
    delay(1000);

    lcd.clear();
    measure();
}

void loop()
{

    // Messsage départ/fonction pour ne pas l'avoir a chaque fois
    buttonState = digitalRead(buttonPin);

    if (Demarrage == 0)
    {

        start();
        Demarrage++;
        Serial.print(Demarrage);
    }

    if (MesureLoop == 1)
    {

        measure();
        delay(1000);


    } 
    
    if (MesureLoop == 0) {

        if (buttonState == LOW){

            lcd.clear();
            lcd.print("Passage en mode");

            lcd.setCursor(3, 1);
            lcd.print("Automatique");

            delay(2000);
            MesureLoop++;
        }
    }
}

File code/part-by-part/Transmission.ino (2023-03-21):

#include <SoftwareSerial.h>
#include <Wire.h>

const int debit = 9600;
SoftwareSerial mySerial(4,3); //RX,TX   connectées sur TX,RX du XBEE


void setup() 
{
  Serial.begin(debit);
  mySerial.begin(debit);
  Serial.println("Test communication RS232 XBEE");
  delay(1000);
}

void loop() 
{
  Serial.println("envoie d'un caractere");
  mySerial.println("AAAAAAAAAAAA");
  delay(1000); 
  } 
  

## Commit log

2023-03-14 update captor current
2023-03-16 update
    Correction lcd code;
    Ajout test multifonction;
    Modification code capteur;
    [butron-lcd-captor.ino, button-lcd.ino, captor.ino]
2023-03-16 Correction
    Correction du code lcd-button
    [butron-lcd-captor.ino, button-lcd.ino]
2023-03-16 DOC
    Ajout de doc et photo
2023-03-18 code assemblé
2023-03-18 Correction
    Nouveau programme
    et organisation fichier
    [button-lcd.ino, captor.ino]
2023-03-25 3D model
    [BAS PROJET (1).stl, BAS PROJET avec aeration.stl]
2023-03-25 fichier stl
    Plan V1 boitier
    [BAS PROJET (1).stl, BAS PROJET avec aeration.stl, bas projet AE.stl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]
2023-03-30 Trame I2C
    Trame I²C ajouté
    organisation
2023-03-30 Problerm pin
2023-05-04 Mise en forme
    [Boitier projet bas.stl, HAUT AS.stl, HAUT SS V2.stl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]
2023-05-09 Fichier 3D
    Retiré
    [Boitier projet bas.stl, HAUT AS.stl, HAUT SS V2.stl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]
2023-05-10 Revert "Fichier 3D"
    This reverts commit b466d89a7a385d0a55969cc0d43c25ebcdf8033b.
    [Boitier projet bas.stl, HAUT AS.stl, HAUT SS V2.stl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]
